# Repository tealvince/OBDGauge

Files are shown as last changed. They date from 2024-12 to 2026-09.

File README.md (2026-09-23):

# vOBD: The K-line Super Gauge
By Vince Lee (c)2024-2026

## Description

This project is a custom OBD cluster gauge and experimentation platform for ECUs 
with a k-line interface, driven by an Arduino nano and intended to be installed 
in a 2" diameter circular pod.

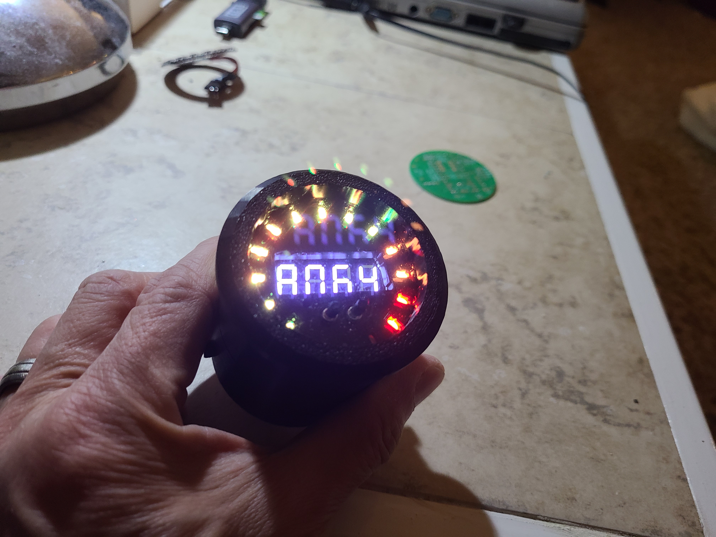
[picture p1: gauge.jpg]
prototype


## Feature overview

* 25 displayable parameters, including instantaneous and cumulative stats
* Metric/Imperial units
* Ability to hide/show individual gauges
* Built-in readiness monitor reader
* Built-in engine code reader
* Built-in menu to clear engine codes
* Adjustable brightness
* Iso-9140, Kwp-2000 (slow) and Kwp-2009 (fast) interfaces
* Numeric display with color led ring
* Persisting of settings with auto-save on power-off
* Auto-detect and cycling of protocols on startup or disconnect
* Custom circuit board layout

## Supported gauges (functionality is vehicle-dependent)

* Battery voltage level
* Accumulated runtime
* Accumulated distance
* Average fuel efficiency
* Average speed
* G-Force
* Wheel Horsepower
* Gear
* NV Ratio (rpm/speed)
* Speed
* Tachometer
* Coolant temp
* Air intake pressure
* Air intake flow
* Throttle percentage
* Engine load
* Timing advance
* Fuel tank level
* Fuel consumption rate
* Air/Fuel trim
* Air/Fuel equivalence ratio
* O2 a/b sensor voltages

## General usage

* Press button 2 to advance to the next gauge.
* Press button 1 to see the previous gauge.
* Long press button 1 to change brightness
* Long press button 2 to open the settings menu.
* Press button 2 to advance to the next item in settings menu.
* Press button 1 to backup to previous item in settings menu.
* Long press button 2 to select an item in the settings menu.

## Settings menu items

* Back (return to main display)

### History
* Erase all (clear cumulative/average gauges)
* Erase cumulative distance
* Erase cumulative fuel
* Erase cumulative time
* Adjust cumulative distance
* Adjust cumulative fuel
* Adjust cumulative time

### Brighness
* brightness levels 1-5

### Gauges
* Toggle current gauge units (metric/us)
* All gauges to SI Units
* All gauges to US Units
* Hide current gauge
* Show gauge (select from list)
* Auto hide/show gauges based on supported PIDs
* See info (dump raw hex data from current gauge)

### Codes
* Check readiness status
* Read codes
* Clear codes

### Values
* Burn adjustment (set multiplier to fine-tune fuel usage/efficiency stats)
* Vehicle weight adjustment (used to calculate HP)
* Show gear NV ratio thresholds
* Start gear auto-detect drive cycle
* Add gear
* Remove gear
* Edit gear threshold (1-8)

### Modes
* Toggle Loop mode (auto-advance gauges) 
* Toggle Demo mode (simulate ECU reponses)
* Toggle Debug mode (show received bytes)
* Enter Sniff mode (listen to K+ line and show received data; use with Y cable and other device)

## Hardware

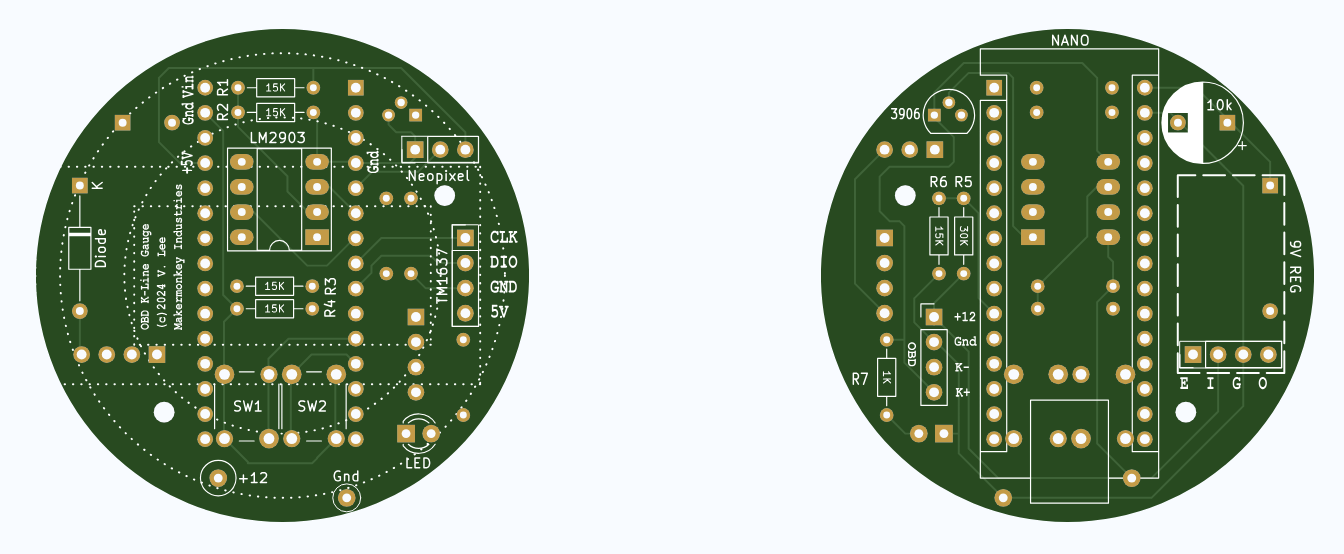
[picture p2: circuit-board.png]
circuit board


* Custom circuit board
* Arduino nano every
* Neopixel 16-LED ring light
* TM1637 4-Digit LED numeric display
* LM2903 Dual comparator IC
* 2N3906 Transistor

## Circuit

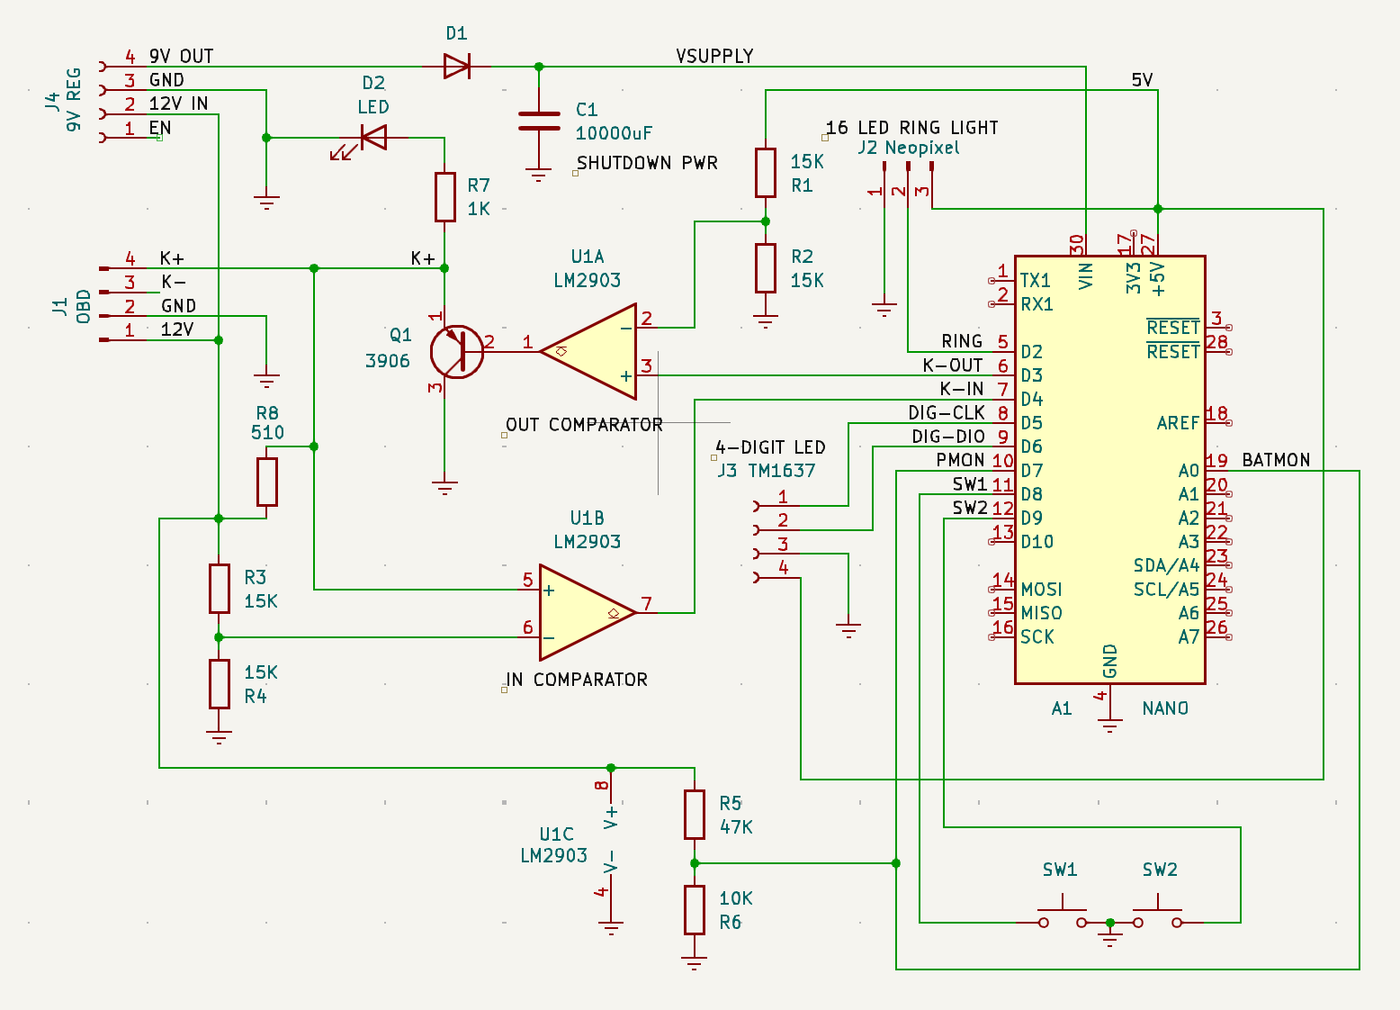
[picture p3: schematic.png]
schematic


To read to and write from the K-Line, a dual comparator chip does the work of converting 
between 5V and 12V logic levels, using voltage dividers to yield 6V and 2.5V reference
voltages.  The output of the "write" comparator goes to a PNP transistor to pull the k-line 
low when sending data back to the PCM, safely sinking more current than the comparator 
can on its own.

To power the arduino, an ignition-switched 12V output is fed to the built-in regulator 
on the Arduino Nano Every (previous iterations used an external voltage regulator with
a plain Arduino Nano, whole upper voltage limit was only 12V).  A large capacitor briefly 
keeps the unit running long enough to save state to persistent memory after the ignition 
is turned off.

## Software

The gauge software is written in C++ with minimal libraries to drive the LED displays.
Serial communication is done with raw bit banging, implementing serial port communication 
purely in software timed off the Arduino microsecond timer.

## Testing

Try out the software or experiment with code changes in a simulated environment using
the following  WOKWI project.  Recommend enabling Demo Mode from the settings menu
since the ECU itself is not simulated:

https://wokwi.com/projects/430523461712229377

## Case

The case and internal spacers and supports are 3D printed.  Stl files are included, as 
well as an svg for the front glass with laser cut holes for the buttons.

Case parts include:

* front glass (laser cut acrylic)
* case body (3d printed)
* case rear (3d printed)
* light mask for led ring (3d printed)
* button extensions (3d printed)
* left and right led digit spacers/supports (3d printed)
* led ring spacer/support (3d printed)

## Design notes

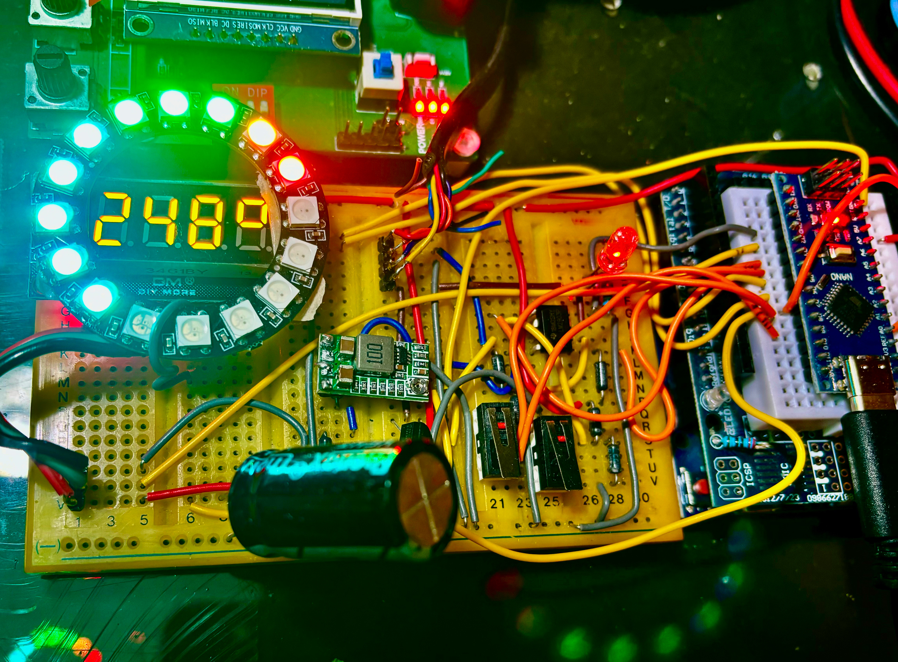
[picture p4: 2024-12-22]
prototype.jpg

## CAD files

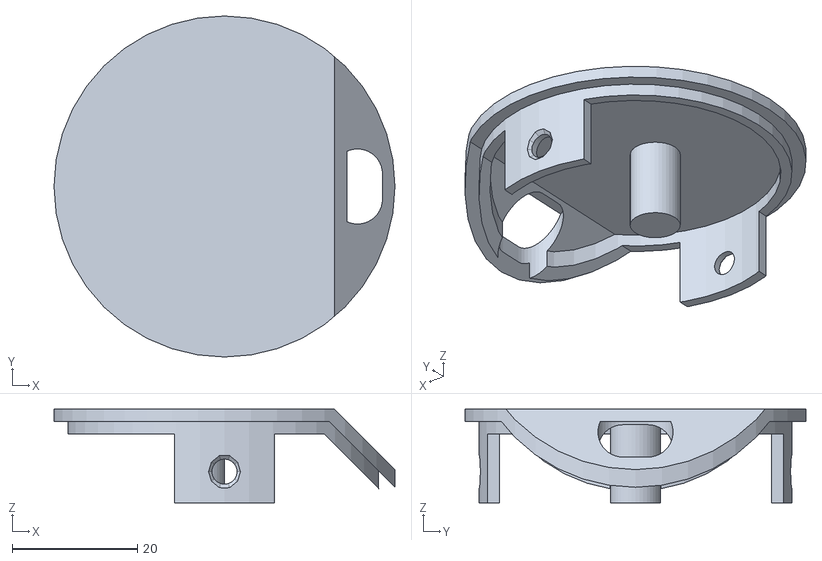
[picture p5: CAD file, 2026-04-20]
src/models/backAngle.stl
54.5 x 54.5 x 15.0

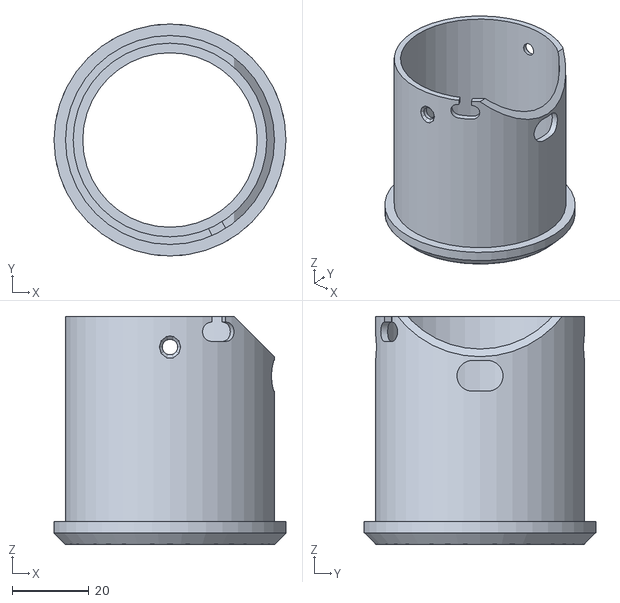
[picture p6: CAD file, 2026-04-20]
src/models/shellAngle.stl
60.5 x 60.5 x 59.5

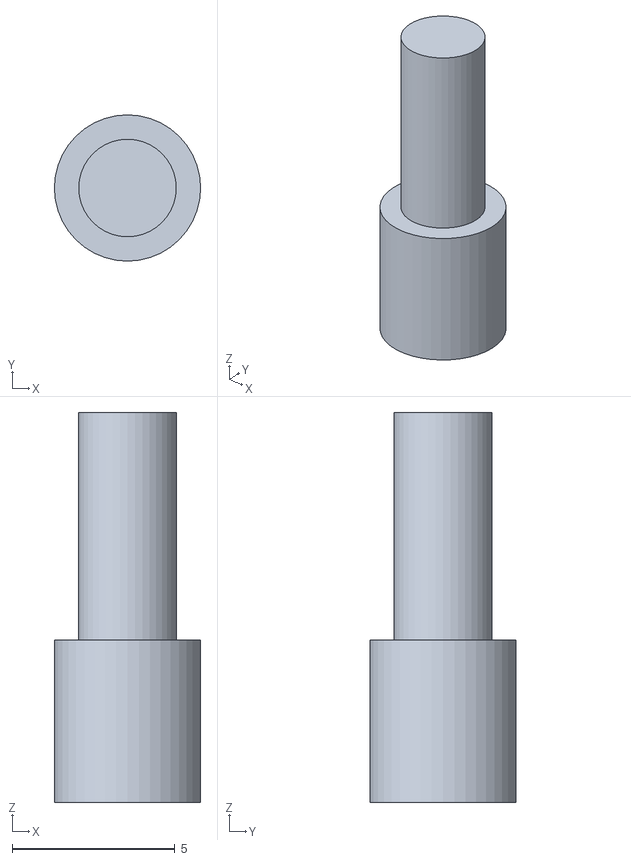
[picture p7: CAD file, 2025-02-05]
src/models/button.stl
4.50 x 4.50 x 12.0

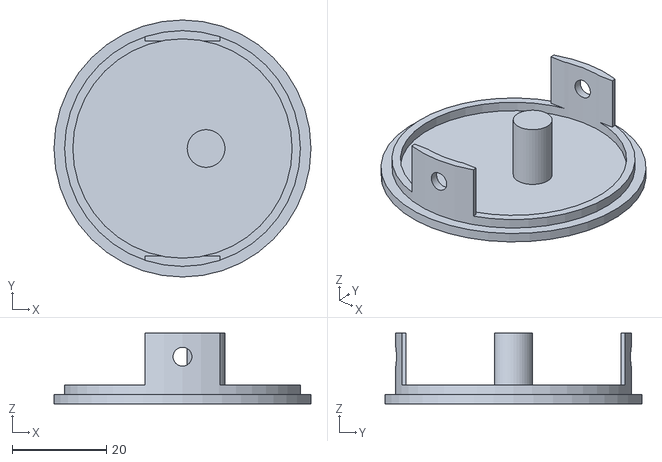
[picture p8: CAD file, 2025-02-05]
src/models/back.stl
54.5 x 54.5 x 15.0

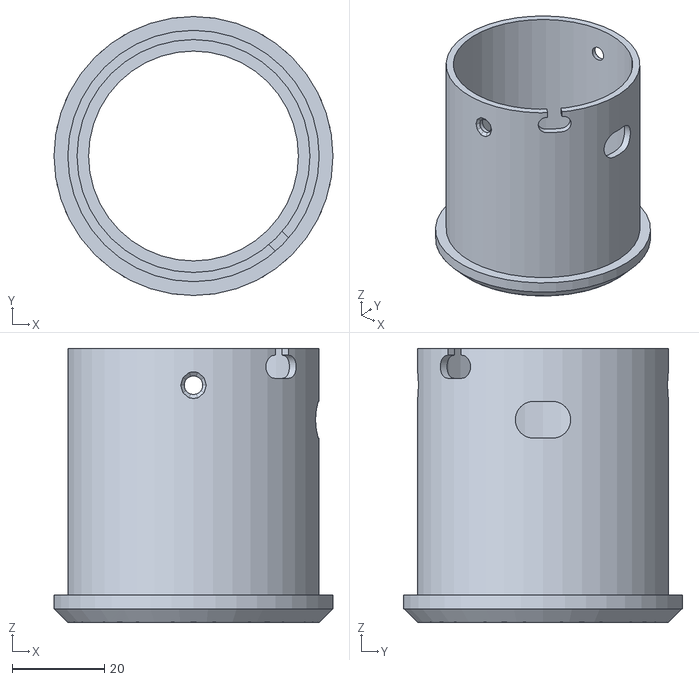
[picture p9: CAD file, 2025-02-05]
src/models/shell.stl
60.5 x 60.5 x 59.5

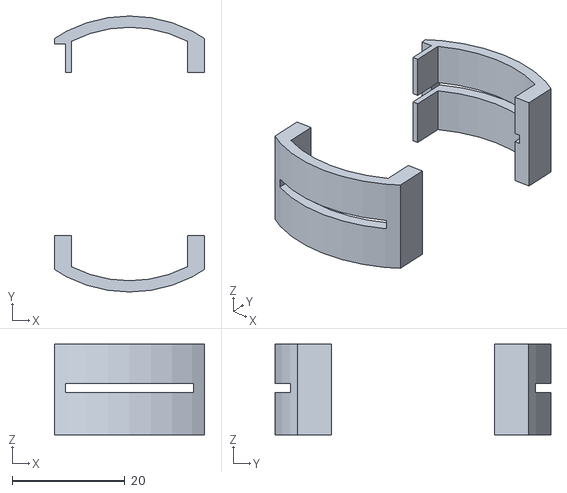
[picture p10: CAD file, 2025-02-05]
src/models/ledSupport.stl
26.6 x 49.0 x 16.1

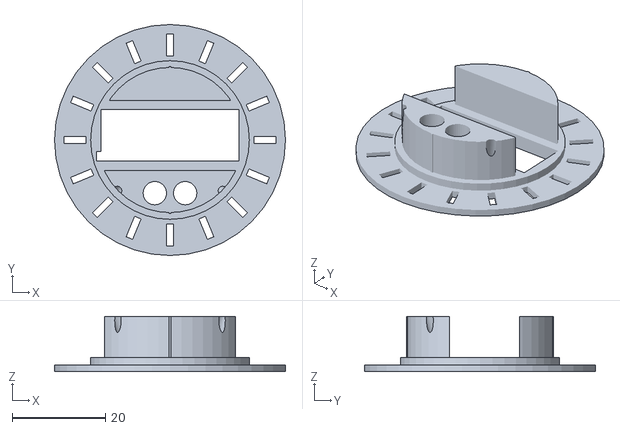
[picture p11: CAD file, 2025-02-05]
src/models/ringSupport.stl
49.5 x 49.5 x 11.8

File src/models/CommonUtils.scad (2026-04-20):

// Rotation
module rotate_x(x,y,z,angle) {
    translate([x,y,z])
        rotate([angle,0,0])
            translate([-x,-y,-z])
                children();
}
module rotate_y(x,y,z,angle) {
    translate([x,y,z])
        rotate([0,angle,0])
            translate([-x,-y,-z])
                children();
}
module rotate_z(x,y,z,angle) {
    translate([x,y,z])
        rotate([0,0,angle])
            translate([-x,-y,-z])
                children();
}

// Oval

module oval(x1, x2, y1, y2, z1, z2) {
	translate([(x1+x2)/2,(y1+y2)/2,z1]) scale([x2-x1,y2-y1,z2-z1]) cylinder(r=0.5,h=1, $fn=40);
}

// Cone
module cone_z(x,y,z1,z2,rad1,rad2) {
   translate([x,y,z1]) {
		cylinder(r1=rad1, r2=rad2, h = z2-z1);
	}
}
module cylinder_x(x1,x2,y,z,rad1,rad2) {

	rounded_box_x(x1,x2,y-rad,y+rad,z-rad,z+rad,rad);
}

// Cylinders

module cylinder_x(x1,x2,y,z,rad) {
	rounded_box_x(x1,x2,y-rad,y+rad,z-rad,z+rad,rad);
}

module cylinder_y(x,y1,y2,z,rad) {
	rounded_box_y(x-rad,x+rad,y1,y2,z-rad,z+rad,rad);
}

module cylinder_z(x,y,z1,z2,rad) {
	rounded_box(x-rad,x+rad,y-rad,y+rad,z1,z2,rad);
}

// Boxes
module rect(x1, x2, y1, y2, z1, z2) {
	box(x1, x2, y1, y2, z1, z2);
}
	
module box(x1, x2, y1, y2, z1, z2) {
	translate([x1,y1,z1]) cube([x2-x1,y2-y1,z2-z1]);
}
                                                                   
// X Boxes

module rounded_box_x(x1, x2, y1, y2, z1, z2, rad) {
	rotate([0,-90,0]) rounded_box_z(z1, z2, y1, y2, -x2, -x1, rad);
}

module half_rounded_box_xup(x1, x2, y1, y2, z1, z2, rad) {
	intersection() {
		box(x1, x2, y1, y2, z1, z2, rad);
		rounded_box_x(x1, x2, y1, y2, z1-rad, z2, rad);
	}
}

module half_rounded_box_xdown(x1, x2, y1, y2, z1, z2, rad) {
	intersection() {
		box(x1, x2, y1, y2, z1, z2, rad);
		rounded_box_x(x1, x2, y1, y2, z1, z2+rad, rad);
	}
}
module half_rounded_box_xfront(x1, x2, y1, y2, z1, z2, rad) {
	intersection() {
		box(x1, x2, y1, y2, z1, z2, rad);
		rounded_box_x(x1, x2, y1, y2+rad, z1, z2, rad);
	}
}

module half_rounded_box_xback(x1, x2, y1, y2, z1, z2, rad) {
	intersection() {
		box(x1, x2, y1, y2, z1, z2, rad);
		rounded_box_x(x1, x2, y1-rad, y2, z1, z2, rad);
	}
}

module quart_rounded_box_xupfront(x1, x2, y1, y2, z1, z2, rad) {
	intersection() {
		box(x1, x2, y1, y2, z1, z2, rad);
		rounded_box_x(x1, x2, y1, y2+rad, z1-rad, z2, rad);
	}
}

module quart_rounded_box_xupback(x1, x2, y1, y2, z1, z2, rad) {
	intersection() {
		box(x1, x2, y1, y2, z1, z2, rad);
		rounded_box_x(x1, x2, y1-rad, y2, z1-rad, z2, rad);
	}
}

module quart_rounded_box_xdownfront(x1, x2, y1, y2, z1, z2, rad) {
	intersection() {
		box(x1, x2, y1, y2, z1, z2, rad);
		rounded_box_x(x1, x2, y1, y2+rad, z1, z2+rad, rad);
	}
}

module quart_rounded_box_xdownback(x1, x2, y1, y2, z1, z2, rad) {
	intersection() {
		box(x1, x2, y1, y2, z1, z2, rad);
		rounded_box_x(x1, x2, y1-rad, y2, z1, z2+rad, rad);
	}
}

// Y Boxes

module rounded_box_y(x1, x2, y1, y2, z1, z2, rad) {
	rotate([90,0,0]) rounded_box_z(x1, x2, z1, z2, -y2, -y1, rad);
}

module half_rounded_box_yup(x1, x2, y1, y2, z1, z2, rad) {
	intersection() {
		box(x1, x2, y1, y2, z1, z2, rad);
		rounded_box_y(x1, x2, y1, y2, z1-rad, z2, rad);
	}
}

module half_rounded_box_ydown(x1, x2, y1, y2, z1, z2, rad) {
	intersection() {
		box(x1, x2, y1, y2, z1, z2, rad);
		rounded_box_y(x1, x2, y1, y2, z1, z2+rad, rad);
	}
}

module half_rounded_box_yleft(x1, x2, y1, y2, z1, z2, rad) {
	intersection() {
		box(x1, x2, y1, y2, z1, z2, rad);
		rounded_box_y(x1, x2+rad, y1, y2, z1, z2, rad);
	}
}

module half_rounded_box_yright(x1, x2, y1, y2, z1, z2, rad) {
	intersection() {
		box(x1, x2, y1, y2, z1, z2, rad);
		rounded_box_y(x1-rad, x2, y1, y2, z1, z2, rad);
	}
}

module quart_rounded_box_yupleft(x1, x2, y1, y2, z1, z2, rad) {
	intersection() {
		box(x1, x2, y1, y2, z1, z2, rad);
		rounded_box_y(x1, x2+rad, y1, y2, z1-rad, z2, rad);
	}
}

module quart_rounded_box_yupright(x1, x2, y1, y2, z1, z2, rad) {
	intersection() {
		box(x1, x2, y1, y2, z1, z2, rad);
		rounded_box_y(x1-rad, x2, y1, y2, z1-rad, z2, rad);
	}
}

module quart_rounded_box_ydownleft(x1, x2, y1, y2, z1, z2, rad) {
	intersection() {
		box(x1, x2, y1, y2, z1, z2, rad);
		rounded_box_y(x1, x2+rad, y1, y2, z1, z2+rad, rad);
	}
}

module quart_rounded_box_ydownright(x1, x2, y1, y2, z1, z2, rad) {
	intersection() {
		box(x1, x2, y1, y2, z1, z2, rad);
		rounded_box_y(x1-rad, x2, y1, y2, z1, z2+rad, rad);
	}
}

// Z Boxes

module rounded_box_z(x1, x2, y1, y2, z1, z2, rad) {
	rect(x1, x2, y1+rad, y2-rad, z1, z2);
	rect(x1+rad, x2-rad, y1, y2, z1, z2);

	oval(x1, x1+rad*2, y1, y1+rad*2, z1, z2);
	oval(x1, x1+rad*2, y2-rad*2, y2, z1, z2);
	oval(x2-rad*2, x2, y2-rad*2, y2, z1, z2);
	oval(x2-rad*2, x2, y1, y1+rad*2, z1, z2);
}

module half_rounded_box_zfront(x1, x2, y1, y2, z1, z2, rad) {
	intersection() {
		box(x1, x2, y1, y2, z1, z2);
		rounded_box_z(x1, x2, y1, y2+rad, z1, z2, rad);
	}
}

module half_rounded_box_zback(x1, x2, y1, y2, z1, z2, rad) {
	intersection() {
		box(x1, x2, y1, y2, z1, z2);
		rounded_box_z(x1, x2, y1-rad, y2, z1, z2, rad);
	}
}

module half_rounded_box_zleft(x1, x2, y1, y2, z1, z2, rad) {
	intersection() {
		box(x1, x2, y1, y2, z1, z2);
		rounded_box_z(x1, x2+rad, y1, y2, z1, z2, rad);
	}
}

module half_rounded_box_zright(x1, x2, y1, y2, z1, z2, rad) {
	intersection() {
		box(x1, x2, y1, y2, z1, z2);
		rounded_box_z(x1-rad, x2, y1, y2, z1, z2, rad);
	}
}

module quart_rounded_box_zfrontleft(x1, x2, y1, y2, z1, z2, rad) {
	intersection() {
		box(x1, x2, y1, y2, z1, z2);
		rounded_box_z(x1, x2+rad, y1, y2+rad, z1, z2, rad);
	}
}

module quart_rounded_box_zfrontright(x1, x2, y1, y2, z1, z2, rad) {
	intersection() {
		box(x1, x2, y1, y2, z1, z2);
		rounded_box_z(x1-rad, x2, y1, y2+rad, z1, z2, rad);
	}
}

module quart_rounded_box_zbackleft(x1, x2, y1, y2, z1, z2, rad) {
	intersection() {
		box(x1, x2, y1, y2, z1, z2);
		rounded_box_z(x1, x2+rad, y1-rad, y2, z1, z2, rad);
	}
}

module quart_rounded_box_zbackright(x1, x2, y1, y2, z1, z2, rad) {
	intersection() {
		box(x1, x2, y1, y2, z1, z2);
		rounded_box_z(x1-rad, x2, y1-rad, y2, z1, z2, rad);
	}
}

// Legacy

module rounded_box(x1, x2, y1, y2, z1, z2, rad) {
	rounded_box_z(x1, x2, y1, y2, z1, z2, rad);
}

module half_rounded_box(x1, x2, y1, y2, z1, z2, rad) {
	half_rounded_box_zfront(x1, x2, y1, y2, z1, z2, rad);
}

module half_rounded_box_x(x1, x2, y1, y2, z1, z2, rad) {
	half_rounded_box_xfront(x1, x2, y1, y2, z1, z2, rad);
}

module half_rounded_box_y(x1, x2, y1, y2, z1, z2, rad) {
	half_rounded_box_yup(x1, x2, y1, y2, z1, z2, rad);
}



// Frustum

// 1(5)  2(6)
// 0(4)  3(7)
module frustrum(dx1,dy1,dx2,dy2,dz1,dz2) {
	frustum(dx1,dy1,dx2,dy2,dz1,dz2);
}
	
module frustum(dx1,dy1,dx2,dy2,dz1,dz2) {
	polyhedron( points=[[-dx1/2,-dy1/2,dz1],
						 [-dx1/2, dy1/2,dz1],
						 [ dx1/2, dy1/2,dz1],
						 [ dx1/2,-dy1/2,dz1],
						 [-dx2/2,-dy2/2,dz2],
						 [-dx2/2, dy2/2,dz2],
						 [ dx2/2, dy2/2,dz2],
						 [ dx2/2,-dy2/2,dz2]],
				 triangles=[[0,2,1],[0,3,2],
							 [0,4,7],[0,7,3],
							 [3,7,6],[3,6,2],
							 [2,6,5],[2,5,1],
							 [1,5,4],[1,4,0],
							 [4,5,6],[4,6,7]] );
}

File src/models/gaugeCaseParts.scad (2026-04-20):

include <commonutils.scad>

button_spacing = 6.5;
button_diam = 4+1;
button_y = -7.5-4.89+1;

ring_retainer_lip_diam = 34;
ring_retainer_lip_thick = 3;
ring_retainer_inner_diam = 30-1.2+2.3;
ring_retainer_height = 10.8-2;
ring_retainer_notch_height = 31.5;
ring_retainer_notch_width = 0.5;

ring_con_x = 12.6;
ring_con_y = 22.5/2;
ring_con_w = 10;
ring_con_h = 3.5;

led_cy = 1;
led_width = 31+.5;
led_height = 15;//-2.7;
led_lip_v_width = 1;
led_lip_h_width = 2;

light_dx = -9;
light_dy = -8.5;
light_hole_diam = 2;
light_rx = 15;
light_ry = -15;

shell_in_lip = 2.5;
shell_out_lip = 3;
shell_diam = 50+0.5;
shell_height = 40+15-4.5;
shell_thick = 2;
shell_glass_thick = 3;
shell_front_thick = 6;
shell_holes_dz = 8;
shell_holes_diam = 4;

usb_depth = 8;
usb_width = 12;
usb_z = 47-3;

// Angled back
back_angle = 45;
back_angle_x = shell_diam/2;
back_angle_z = usb_z+usb_depth/2+3;

obd_width = 9.3;
obd_depth = 5;
obd_angle = 180-45-90+17;
obd_z = shell_height + shell_glass_thick + shell_front_thick + shell_thick - obd_depth - 1;

//button();
// ring_retainer();

color("blue") shell();

//rotate([180])
//  translate([0,0,20])
//      color("red") back();

//led_support();
//  grille();

module led_support() {    
    diam = 49;
    height = 7.5;
    thick = 2;
    depth = 10;
    
    board_width = 22.15+.25+.25;
    board_thick = 1.6;

    difference() {
        intersection() {
            cylinder_z(0,0,0,height+board_thick+thick+5, diam/2);
            box(-board_width/2-thick, board_width/2+thick, -100, 100, -100, 100);
        }
        intersection() {
            cylinder_z(0,0,0,height+board_thick+thick+5, diam/2-thick);
            box(-board_width/2+1, board_width/2-1, -100, 100, -100, 100);
        }
        box(-board_width/2, board_width/2, -100, 100, height, height+board_thick);
        box(-100,100, -diam/2+depth, diam/2-depth, -100,100);
        box(-100,-board_width/2, 0, diam/2-5, -100,100);
    }
}

module grille() {
    inner_diam = 34;
    outer_diam = 49.5;
    thick = 2.8;
    slit = 2.5-1;
    
    translate([0,0,-ring_retainer_lip_thick])
    difference() {
        cylinder_z(0,0,0,thick/2,outer_diam/2);
        cylinder_z(0,0,thick/2,thick,outer_diam/2-2);
        cylinder_z(0,0,0,thick,inner_diam/2);
        for (angle = [0: 360/16: 360]) rotate([0,0,angle]) {
            box(-slit/2,slit/2, inner_diam/2+1, outer_diam/2-2, 0,thick+2);
        }
    }
}

module back() {
    
    // center post support
    cylinder_z(-4, 0,
        shell_height + shell_glass_thick + shell_front_thick - 13, 
        shell_height + shell_glass_thick + shell_front_thick + shell_thick,
                4);

    // Angled back
    difference() {
        union() {
            // outer
            difference() {
                intersection() {
                    translate([back_angle_x,0,back_angle_z])
                        rotate([0, back_angle, 0])
                            box(-100,100,-100,100,0,100);
                    cylinder_z(0,0,
                        0, 
                        shell_glass_thick + shell_front_thick+shell_height+shell_thick,
                        shell_diam/2+shell_thick);
                }

                translate([back_angle_x,0,back_angle_z])
                    rotate([0, back_angle, 0])
                        box(-100,100,-100,100,shell_thick,100);
            }       
            // inner 
            intersection() {
                difference() {
                    cylinder_z(0,0,
                        0, 
                        shell_glass_thick + shell_front_thick+shell_height+shell_thick,
                        shell_diam/2-.25);
                    cylinder_z(0,0,
                        0, 
                        shell_glass_thick + shell_front_thick+shell_height+shell_thick,
                        shell_diam/2-shell_thick);
                }
                translate([back_angle_x,0,back_angle_z])
                    rotate([0, back_angle, 0])
                        box(-100,100,-100,100,-shell_thick,.01);
            }        
        }
        rounded_box_z(shell_diam/2-usb_depth, shell_diam/2,
            -usb_width/2, usb_width/2, -100,100, usb_depth/2);
    }
    
    difference() {
        union() {
            // Inner
            cylinder_z(0,0,
                shell_height+ shell_glass_thick + shell_front_thick-shell_holes_dz-5, 
                shell_glass_thick + shell_front_thick+shell_height+shell_thick,
                shell_diam/2-.25);
            
            // lid
            cylinder_z(0,0,
                shell_glass_thick + shell_front_thick+shell_height,
                shell_glass_thick + shell_front_thick+shell_height+shell_thick,
                shell_diam/2+shell_thick);

        }
        // Angled Back
        translate([back_angle_x,0,back_angle_z])
            rotate([0, back_angle, 0])
                box(-100,100,-100,100,shell_thick,100);

        // tab cutouts
        box(-100,-8, -100,100, 0, shell_height+ shell_glass_thick + shell_front_thick-shell_thick);
        box(8, 100, -100,100, 0, shell_height+ shell_glass_thick + shell_front_thick- shell_thick);
        box(-100, 100, -shell_diam/2+2.5+2, shell_diam/2-2.5-2, 0, shell_height+ shell_glass_thick + shell_front_thick- shell_thick);

        // inner circle
            cylinder_z(0,0,0,
                    shell_glass_thick + shell_front_thick+shell_height,
                    shell_diam/2-shell_thick);
        
        // Screw holes
        translate([0, -shell_diam/2-shell_thick+2, 
            shell_height+ shell_glass_thick + shell_front_thick-shell_holes_dz]) 
                rotate([-90]) shell_hole();
        mirror([0,1,0]) 
            translate([0, -shell_diam/2-shell_thick+2, 
            shell_height+ shell_glass_thick + shell_front_thick-shell_holes_dz]) 
                rotate([-90]) shell_hole();
    }
}    

module shell() {
    difference(){
        union() {
            cylinder_z(0,0,0, 
                shell_height + shell_glass_thick + shell_front_thick,
                shell_diam/2+shell_thick);
            cylinder(
                r1 = shell_diam/2+shell_thick, 
                r2 = shell_diam/2+shell_thick+shell_out_lip,
                h = shell_front_thick/2);
            cylinder_z(0,0,shell_front_thick/2-.01, 
                shell_front_thick,
                shell_diam/2+shell_thick+shell_out_lip);
        }
        cylinder_z(0,0,
            shell_front_thick-.01, 
            shell_glass_thick + shell_front_thick+shell_height+.01,
            shell_diam/2);
        cylinder_z(0,0,-0.01,
            shell_front_thick,
            shell_diam/2-shell_in_lip);

        // usb port
        rounded_box_x(0, 100, -usb_width/2, usb_width/2,
            usb_z-usb_depth/2, usb_z+usb_depth/2, usb_depth/2);
        
        // obd port
        rotate([0,0,obd_angle]) union() {
            rounded_box_x(0, 100, -obd_width/2, obd_width/2,
                obd_z-obd_depth/2, obd_z+obd_depth/2, obd_depth/2);
            box(0, 100, -2, 2,
                obd_z-obd_depth/2, obd_z+obd_depth/2+5);
        }
        
        // Screw holes
        translate([0, -shell_diam/2-shell_thick, 
            shell_height+ shell_glass_thick + shell_front_thick-shell_holes_dz]) 
                rotate([-90]) shell_hole();
        mirror([0,1,0]) 
            translate([0, -shell_diam/2-shell_thick, 
            shell_height+ shell_glass_thick + shell_front_thick-shell_holes_dz]) 
                rotate([-90]) shell_hole();
        
        // Angled back
        
        translate([back_angle_x,0,back_angle_z])
            rotate([0, back_angle, 0])
                box(-100,100,-100,100,0,100);
    }
} 

module shell_hole() {
        cylinder_z(0,0,0,
            shell_thick*2+1,
            shell_holes_diam/2);
        cylinder(
            r1 = shell_holes_diam/2+shell_thick/2, 
            r2 = shell_holes_diam/2,
            h = shell_thick/2);

}

module button() {
    cylinder_z(0,0,0,5, 4.5/2);
    cylinder_z(0,0,0,12, 3/2);

}
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

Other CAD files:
src/models/shellAngleFlip.stl

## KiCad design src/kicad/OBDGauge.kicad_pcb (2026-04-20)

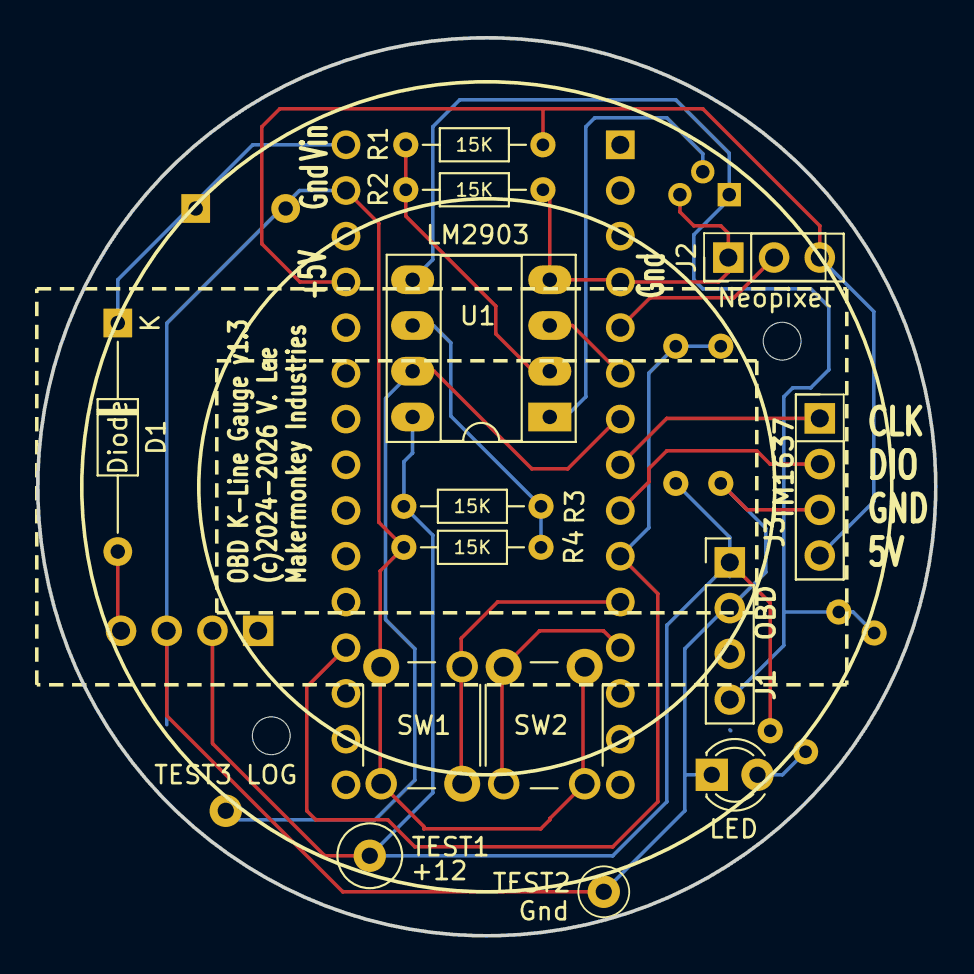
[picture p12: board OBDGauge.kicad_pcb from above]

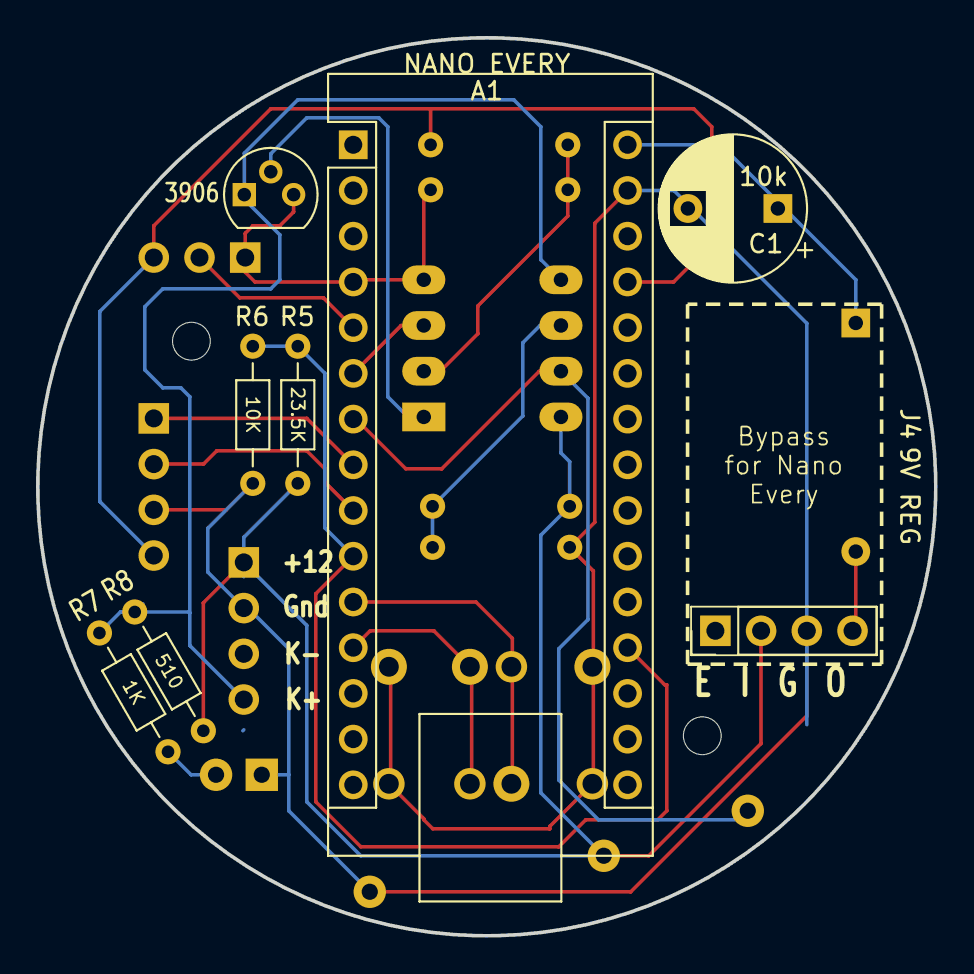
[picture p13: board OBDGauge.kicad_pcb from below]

Board: 2 copper layers, 49.9 x 49.9 mm, 25 parts (8 on the bottom side), 18 nets.

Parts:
A1: NANO EVERY; Arduino_Nano
C1: 10000uF; CP_Radial_D8.0mm_P5.00mm
D1: Diode; D_DO-35_SOD27_P12.70mm_Horizontal
D2: LED; LED_D3.0mm
HOLE1, HOLE2: MountingHole_2.1mm
J1: OBD; PinHeader_1x04_P2.54mm_Vertical
J2: Neopixel; PinHeader_1x03_P2.54mm_Vertical
J3: TM1637; PinHeader_1x04_P2.54mm_Vertical
J4: 9V REG; PinHeader_1x04_P2.54mm_Vertical
Q1: 3906; TO-92
R1, R2, R3, R4, R6: 15K; R_Axial_DIN0204_L3.6mm_D1.6mm_P7.62mm_Horizontal
R5: 30K; R_Axial_DIN0204_L3.6mm_D1.6mm_P7.62mm_Horizontal
R7: 1K; R_Axial_DIN0204_L3.6mm_D1.6mm_P7.62mm_Horizontal
R8: 10K; R_Axial_DIN0204_L3.6mm_D1.6mm_P7.62mm_Horizontal
SW1: SW1; SW_PUSH_6mm_H8.5mm
SW2: SW2; SW_PUSH_6mm_H8.5mm
TEST1: +12; TestPoint_Loop_D3.50mm_Drill0.9mm_Beaded
TEST2, TEST3 LOG: GND
U1: LM2903; DIP-8_W7.62mm_Socket_LongPads

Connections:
/5V: A1.27 (+5V), J2.3, J3.4, R1.2
/9V OUT: D1.2 (A), J4.4
/12V: J1.1, J4.2, R3.1, R5.1, R8.2, TEST1.1, U1.8 (V+)
/BATMON: A1.10 (D7), A1.19 (A0), R5.2, R6.2
/DIG-CLK: A1.8 (D5), J3.1
/DIG-DIO: A1.9 (D6), J3.2
/K+: J1.4, Q1.1 (E), R7.1, R8.1, U1.5 (+)
/K-IN: A1.7 (D4), TEST3 LOG.1, U1.7
/K-OUT: A1.6 (D3), U1.3 (+)
/RING: A1.5 (D2), J2.2
/SW1: A1.11 (D8), SW1.2
/SW2: A1.12 (D9), SW2.2
/VSUPPLY: A1.30 (VIN), C1.1, D1.1 (K)
GNDREF: A1.4 (GND), A1.29 (GND), C1.2, D2.1 (K), J1.2, J2.1, J3.3, J4.3, Q1.3 (C), R2.2, R4.1, R6.1, SW1.1, SW2.1, TEST2.1, U1.4 (V-)
unnamed: D2.2 (A), R7.2
unnamed: Q1.2 (B), U1.1
unnamed: R1.1, R2.1, U1.2 (-)
unnamed: R3.2, R4.2, U1.6 (-)

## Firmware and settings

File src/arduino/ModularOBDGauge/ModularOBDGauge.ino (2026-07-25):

#include "Environment.h"
#include "VDigits.h"
#include "VDisplayables.h"
#include "VRing.h"

//
// MODULAROBDGAUGE.INO
//

#define DIGITS_PIN_CLK      5
#define DIGITS_PIN_DIO      6
#define DIGITS_BRIGHTNESS_MAX 7
#define DIGITS_BRIGHTNESS_MIN 2

#define OBD_OUT_PIN         3
#define OBD_IN_PIN          4

#define POWER_PIN           7
#define POWER_ANALOG_PIN    A0

#define RING_PIN_CONTROL    2
#define RING_LIGHT_COUNT    16
#define RING_ROTATION_OFFSET (WOKWI ? 7 : 0)
#define RING_STATUS_COUNT   3
#define RING_BRIGHTNESS     25
#define RING_BRIGHTNESS_MAX (WOKWI ? 255 : 40)
#define RING_BRIGHTNESS_MIN 4

#define SWITCH_PIN_1        9
#define SWITCH_PIN_2        8
#define LED_PIN             13

VDigits vdigits;
VDisplayables vdisplayables;
VRing vring;

// Forward declarations
bool ap_isControlsButton1Down();
bool ap_isControlsButton2Down();
void ap_menuItemHighlight(int current, char color, int count, MenuDataSource *ds);
void ap_menuItemShowTitle(char *title);
int  ap_getDisplayBarCount(void);
void ap_setDisplayBarColor(int index, unsigned char color);
void ap_showDisplayBar();
void ap_showDisplayFloatValue(float num, int decimals, int suffix, bool addPlus);
void ap_showDisplayStatusState(bool connecting, bool resetting, int errorCount, int connectionErrorCount, int protocolIndex);
void ap_showDisplayStatusString(char *text);
void ap_showDisplayStatusString_P(char *ptext);
void ap_showSweep(char color, int mode);
void ap_setDisplayBrightness(int brightness);
void ap_smartDelay(unsigned long wait);

struct MenuControlsProvider app_menuControlsProvider = {
  ap_isControlsButton1Down,
  ap_isControlsButton2Down,
  ap_smartDelay
};

struct MenuDisplayProvider app_menuDisplayProvider = {
  ap_menuItemHighlight,
  ap_menuItemShowTitle,
};

struct DisplayablesOutputProvider app_displayablesOutputProvider = {
  ap_getDisplayBarCount,
  ap_setDisplayBarColor,
  ap_showDisplayBar,
  ap_showDisplayFloatValue,
  ap_showDisplayStatusState,
  ap_showDisplayStatusString,
  ap_showDisplayStatusString_P,
  ap_showSweep,
  ap_setDisplayBrightness,
};

void setup() {
 
  // Setup
  pinMode(POWER_PIN, INPUT);
  pinMode(SWITCH_PIN_1, INPUT_PULLUP);
  pinMode(SWITCH_PIN_2, INPUT_PULLUP);
  vdigits.setup(DIGITS_PIN_CLK, DIGITS_PIN_DIO);
  vring.setup(RING_PIN_CONTROL, RING_LIGHT_COUNT, RING_BRIGHTNESS, RING_ROTATION_OFFSET);

  ap_showDisplayStatusString_P(PSTR("VObd"));
  ap_showSweep('c', SWEEP_MODE_RIGHT_LEFT);
  ap_smartDelay(800);
  ap_showDisplayStatusString_P(PSTR(" " BUILD_VERSION));
  ap_smartDelay(800);
  vring.clear();

  vdisplayables.setup(OBD_IN_PIN, OBD_OUT_PIN, POWER_ANALOG_PIN, &app_displayablesOutputProvider, &app_menuDisplayProvider, &app_menuControlsProvider);
}

void loop() {
  vdisplayables.mainLoop();
}

///////////////////////////////////////////////////////////////
// APP GLUE
///////////////////////////////////////////////////////////////

//------------------------------------------------------
// Private
//------------------------------------------------------

#define BUTTON_DEBOUNCE_COUNT 12
static bool ap_button1LastState = false;
static bool ap_button2LastState = false;

bool ap_isControlsButton1Down() {
  bool state = !digitalRead(SWITCH_PIN_1);
  digitalWrite(LED_PIN, state);

  if (state != ap_button1LastState) {
    for (int i=0; i<BUTTON_DEBOUNCE_COUNT; i++) {
      if (!digitalRead(SWITCH_PIN_1) != state) return ap_button1LastState;
      ap_smartDelay(1);
    }
    return ap_button1LastState = state;
  }

  // Kind of hacky, but ping when reading buttons to keep connection alive
  vdisplayables.ping();

  return ap_button1LastState;
}

bool ap_isControlsButton2Down() {
  bool state = !digitalRead(SWITCH_PIN_2);
  if (state != ap_button2LastState) {
    for (int i=0; i<BUTTON_DEBOUNCE_COUNT; i++) {
      if (!digitalRead(SWITCH_PIN_2) != state) return ap_button2LastState;
      ap_smartDelay(1);
    }
    return ap_button2LastState = state;
  }
  return ap_button2LastState;
}

void ap_menuItemHighlight(int current, char color, int count, MenuDataSource *ds) {
  int iCur = (current + RING_STATUS_COUNT) % RING_LIGHT_COUNT;

  // Show current entry in ring
  for (int i = 0; i < RING_LIGHT_COUNT; i++) {
    if (i == iCur) {
      vring.setPixelColor(i, color);
    } else if (i >= RING_STATUS_COUNT && i < RING_STATUS_COUNT + count || (RING_STATUS_COUNT + count > RING_LIGHT_COUNT && i < (RING_STATUS_COUNT + count) % RING_LIGHT_COUNT)) {
      int delta = i - iCur;

      if (delta > RING_LIGHT_COUNT/2 && current + delta - RING_LIGHT_COUNT >= 0) {
        delta -= RING_LIGHT_COUNT;
      } else if (delta < -RING_LIGHT_COUNT/2 && current + delta + RING_LIGHT_COUNT < count) {
        delta += RING_LIGHT_COUNT;
      }
      int index = current + delta;
      // Show wrapping limits as gap      
      if (index == -1 || index == count) {
        vring.setPixelColor(i, 'k');
      } else if (index == -2 || index == count+1) {
        vring.setPixelColor(i, '-');
      } else if (index == -3 || index == count+2) {
        vring.setPixelColor(i, '+');
      } else {
        vring.setPixelColor(i, index >=0 && index < count ? ds->getItemColor(index, current, ds) : ds->defaultColor);
      }
    } else {
      vring.setPixelColor(i, 'k');
    }
  }
  vring.show();
}

void ap_menuItemShowTitle(char *title) {
  vdigits.showString(title, true);
}

int ap_getDisplayBarCount(void) {
  return RING_LIGHT_COUNT - RING_STATUS_COUNT;
}

void ap_setDisplayBarColor(int index, unsigned char color) {
  vring.setPixelColor(index + RING_STATUS_COUNT, color);
}

void ap_showDisplayBar() {
  vring.show();
}

void ap_showDisplayFloatValue(float num, int dig, int suf, bool addPlus) {
  char sufBuf[2];
  char preBuf[2];
  char *prefix = preBuf; prefix[0] = (num < 0) ? '-' : addPlus ? '+' : 0;

  char suffix = 0;
  unsigned long whole = 0;
  unsigned long frac = 0;
  int fracdig = 0;

  sufBuf[1] = 0;
  preBuf[1] = 0;
  num = fabs(num);

  if (num > 999000000) {
    whole = num/1000000000;
    frac = (num-whole*1000000000)/100000000;
    fracdig = 1;
    suffix = 'B';
  } else if (num > 999000) {
    whole = num/1000000;
    frac = (num-whole*1000000)/100000;
    fracdig = 1;
    suffix = 'M';
  } else if (num > 9999) {
    whole = num/1000;
    frac = (num-whole*1000)/100;
    fracdig = 1;
    suffix = 'k';
  } else {
    whole = num;
    if (dig > 0) {
      float diff = fabs(num) - floor(fabs(num));
      for (int i=0; i<dig; i++) {
        diff *= 10;
      }
      frac = diff;
      fracdig = dig;
    }
  }

  char buf[30];
  char tmp[30];

  strcpy(buf, prefix);
  itoa(whole, buf+strlen(buf), 10);

  int maxDigits = 4;

  // Override default suffix if set
  sufBuf[0] = suffix ?: suf;

  if (strlen(buf) + strlen(sufBuf) + 1 <= maxDigits && ((strlen(sufBuf) && suffix) || dig)) {
    maxDigits++;
    strncat(buf, ".", sizeof(buf)-1);
    itoa(frac, tmp, 10);
    for (int i=strlen(tmp); i<fracdig; i++) {
      strncat(buf, "0", sizeof(buf)-1);
    }
    strncat(buf, tmp, sizeof(buf)-1);
  }

  // Right justify
  int space = maxDigits - strlen(buf) - strlen(sufBuf);
  space = max(0, space);
  tmp[0] = tmp[1] = tmp[2] = tmp[3] = ' ';
  tmp[4] = 0;
  strcpy(tmp+space, buf);

  strncat(tmp, sufBuf, sizeof(tmp)-1);
  vdigits.showString(tmp, true);
}

void ap_showDisplayStatusState(bool connecting, bool resetting, int errorCount, int connectionErrorCount, int protocolIndex) {
  bool powerOn = digitalRead(POWER_PIN);

  for (int i=0; i<RING_STATUS_COUNT; i++) {
    if (!powerOn) {
      vring.setPixelColor(i, 'o');
    } else if (connecting) {
      vring.setPixelColor(RING_STATUS_COUNT-i-1, (i == protocolIndex % RING_STATUS_COUNT) ? 'b' : 'I');
    } else if (resetting) {
      vring.setPixelColor(i, i <= RING_STATUS_COUNT-connectionErrorCount ? 'V' : 'p');
    } else {
      vring.setPixelColor(RING_STATUS_COUNT-i-1, i < errorCount ? 'R' : 'k');
    }
  }
  vring.show();
}

void ap_showDisplayStatusString(char *text) {
  vdigits.showString(text, true);
}

void ap_showDisplayStatusString_P(char *ptext) {
  char text[20];
  strcpy_P(text, ptext);
  ap_showDisplayStatusString(text);
}

void ap_showSweep(char color, int mode) {
  int lightCount = ap_getDisplayBarCount();

  switch(mode) {
    case SWEEP_MODE_UP:
      for (int j = 0; j <= lightCount/2; j++) {
        for (int i = 0; i < lightCount; i++) {    
          ap_setDisplayBarColor(i, i==j || i==lightCount-1-j ? color : 'k');
        }
        ap_showDisplayBar(); 
        ap_smartDelay(40);
      }
      ap_setDisplayBarColor(lightCount/2, 'k');
      break;

    case SWEEP_MODE_DOWN:
      for (int j = lightCount/2; j >= 0; j--) {    
        for (int i = 0; i < lightCount; i++) {    
          ap_setDisplayBarColor(i, i==j || i==lightCount-1-j ? color : 'k');
        }
        ap_showDisplayBar(); 
        ap_smartDelay(40);
      }
      ap_setDisplayBarColor(0, 'k');
      ap_setDisplayBarColor(lightCount-1, 'k');
      break;

    case SWEEP_MODE_RIGHT_LEFT:
    default:
      for (int j = 0; j < lightCount; j++) {    
        for (int i = 0; i < lightCount; i++) {    
          ap_setDisplayBarColor(i, i==j ? color : 'k');
        }
        ap_showDisplayBar(); 
        ap_smartDelay(40);
      }
      for (int j = lightCount-1; j >= 0; j--) {    
        for (int i = 0; i < lightCount; i++) {    
          ap_setDisplayBarColor(i, i==j ? color : 'k');
        }
        ap_showDisplayBar(); 
        ap_smartDelay(40);
      }
      ap_setDisplayBarColor(0, 'k');
      break;
  }
  ap_showDisplayBar(); 
}

void ap_setDisplayBrightness(int brightness) {
  vring.setBrightness(RING_BRIGHTNESS_MIN + (RING_BRIGHTNESS_MAX - RING_BRIGHTNESS_MIN) * brightness/100);
  vdigits.setBrightness(DIGITS_BRIGHTNESS_MIN + (DIGITS_BRIGHTNESS_MAX - DIGITS_BRIGHTNESS_MIN) * brightness/100);
}

static bool ap_lastPowerOn;
void ap_smartDelay(unsigned long wait) {
  unsigned long start = millis();
  while (1) {
    // Detect changes in input power
    bool powerOn = digitalRead(POWER_PIN);
    if (ap_lastPowerOn != powerOn) {
      ap_lastPowerOn = powerOn;
      if (!powerOn) {
        vdigits.showString("Lo-V", true);
        if (vdisplayables.savePersistedState()) {
          vdigits.showString("Save", true);
          delay(1000);
        }
      }
    }

    unsigned long time = millis();
    if (time < start || time >= start + wait) return;

    // Don't block UI for extended periods of time
    if (time >= start + 100 && ap_isControlsButton1Down()) return;
  }
}

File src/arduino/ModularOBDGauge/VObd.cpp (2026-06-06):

#include "VDisplayables.h" // for sweep enums
#include "VObd.h"
#include <Arduino.h>

///////////////////////////////////////////////////////////////
// VOBD.CPP
// Obd protocol handling
///////////////////////////////////////////////////////////////

// KWP Key value bits
#define KWP_KEY1_LENGTH_IN_FORMAT_BYTE_SUPPORTED     0x01
#define KWP_KEY1_ADDITIONAL_LENGTH_BYTE_SUPPORTED    0x02
#define KWP_KEY1_ONE_BYTE_HEADER_SUPPORTED           0x04
#define KWP_KEY1_TARGET_SOURCE_BYTE_SUPPORTED        0x08
#define KWP_KEY1_NORMAL_TIMING_SUPPORTED             0x10
#define KWP_KEY1_EXTENDED_TIMING_SUPPORTED           0x20
#define KWP_KEY1_UNUSED_ALWAYS_ONE                   0x40
#define KWP_KEY1_PARITY                              0x80

#define KWP_MESSAGE_FORMAT_ONE_BYTE_HEADER_LENGTH_IN_FORMAT   0
#define KWP_MESSAGE_FORMAT_ONE_BYTE_HEADER_ADDITIONAL_LENGTH  1
#define KWP_MESSAGE_FORMAT_ADDRESS_HEADER_LENGTH_IN_FORMAT    2
#define KWP_MESSAGE_FORMAT_ADDRESS_HEADER_ADDITIONAL_LENGTH   3

//------------------------------------------------------
// Public (Connect)
//------------------------------------------------------

extern void VObd::setup(int in, int out, void (*delay)(unsigned long), struct ObdOutputProvider *optionalOutputProvider) {
  output = optionalOutputProvider;
  vserial.setup(in, out, delay);
  smartDelay = delay;
}

extern void VObd::connect(int proto, bool demoMode) {
  switch (proto) {
    case OBD_PROTOCOL_ISO_9141:
    case OBD_PROTOCOL_KWP_SLOW:
      if (proto = kwpSlowInit(proto, demoMode)) {
        protocol = proto;
      }
      break;
    case OBD_PROTOCOL_KWP_FAST:
      if (proto = kwpFastInit(proto)) {
        protocol = proto;
      }
      break;
  }
  if (protocol) {
    lastPidRequestTime = millis();
  }
}

extern void VObd::disconnect() {
  protocol = 0;
}

extern bool VObd::isConnected() {
  return protocol != 0;
}

extern void VObd::ping() {
  // Periodically send request to keep connection alive
  if (isConnected() && ((long)(millis() - lastPidRequestTime)) > QUERY_MAX_INTERVAL) {
      sendPidRequest(0x00, 1);
  }
}

extern bool VObd::resetConnection() {
  unsigned long start = micros();

  // Send a bunch of nulls to force the ECU to wait for initialization.
  // By happenstance this was found to work on ECU simulator.  Unsure
  // how effective or necessary this is on a real ECU.
  vserial.sendByteRepeatedly(0, 256, 10400L, 0);
  smartDelay(2600);
}

//------------------------------------------------------
// Public (Query)
//------------------------------------------------------

extern int VObd::sendPidRequest(unsigned char pid, int mode) {
  char bytes[20];
  int count = 0;
  int length = (pid || (mode == 1)) ? 2 : 1;
  unsigned long time = millis();
  long wait = lastPidRequestTime + QUERY_MIN_INTERVAL - time;

  // Enforce minimum time between receiving last request and sending new one
  if (wait > 0 && wait <= QUERY_MIN_INTERVAL) {
    smartDelay(wait);
  }
  // Save time for pinging
  lastPidRequestTime = time;

  switch (protocol) {
    case OBD_PROTOCOL_ISO_9141:
      // Example: 68 6A F1 01 00 C4 

      bytes[count++] = 0x68;  // Diagnostic request
      bytes[count++] = 0x6A;  // Target (ECU)
      bytes[count++] = 0xF1;  // Source (Diagnostic device)
      break;

    case OBD_PROTOCOL_KWP_SLOW:
    case OBD_PROTOCOL_KWP_FAST:

      // One byte header with length in format
      if ((keyByte1 & KWP_KEY1_ONE_BYTE_HEADER_SUPPORTED) && (keyByte1 & KWP_KEY1_LENGTH_IN_FORMAT_BYTE_SUPPORTED)) {
        messageFormat = KWP_MESSAGE_FORMAT_ONE_BYTE_HEADER_LENGTH_IN_FORMAT;
        bytes[count++] = length;
      }

      // One byte header with external length byte
      else if ((keyByte1 & KWP_KEY1_ONE_BYTE_HEADER_SUPPORTED)) {
        messageFormat = KWP_MESSAGE_FORMAT_ONE_BYTE_HEADER_ADDITIONAL_LENGTH;
        bytes[count++] = 0x00;  // empty
        bytes[count++] = length;
      }

      // Address header with format length byte
      else if ((keyByte1 & KWP_KEY1_LENGTH_IN_FORMAT_BYTE_SUPPORTED)) {
        messageFormat = KWP_MESSAGE_FORMAT_ADDRESS_HEADER_LENGTH_IN_FORMAT;
        bytes[count++] = 0xC0 | length;  // 80 = address information, 40 = functional addressing, length = 2
        bytes[count++] = 0x33;  // target (engine)
        bytes[count++] = 0xf1;  // source (diagnostic tools F0-FD)
      }

      // Address header with external length byte
      else {
        messageFormat = KWP_MESSAGE_FORMAT_ADDRESS_HEADER_ADDITIONAL_LENGTH;
        bytes[count++] = 0xc0;  // 80 = address information, 40 = functional addressing
        bytes[count++] = 0x33;  // target
        bytes[count++] = 0xf1;  // source (diagnostic tools F0-FD)
        bytes[count++] = length;
      }
      break;
  }

  bytes[count++] = mode;  // data1: mode
  if (pid || (mode == 1)) {
    bytes[count++] = pid;   // data2: pid
  }
  bytes[count] = getChecksum(bytes, 0, count-1);
  vserial.sendBytes(bytes, count+1, 10400, QUERY_SEND_DELAY_BETWEEN_BYTES);
}

extern long VObd::receivePidResponse(unsigned char pid, int mode, bool showErrors, int debugMode) {
  unsigned char bytes[4];
  int byteCount = receivePidResponseData(bytes, 4, pid, mode, showErrors, debugMode);
  long value = 0;

  lastPidRequestTime = millis();

  if (byteCount > 0) {
    for (int i = 0; i<byteCount && i<4; i++) {
      value = (long)bytes[i] | (value << 8);
    }
  } else {
    return byteCount;
  }
  return value;
}
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

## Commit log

2024-12-25 Update battery level multiplier
2024-12-25 Update battery voltage divider and add k+ pullup
2025-07-06 Add files via upload
    Fixed shift and mask values
    [ModularOBDGauge.ino, VObd.cpp]
2026-04-20 Added gear, horsepower, and g-force gauges
    * Added gear indicator
    * Added horsepower indicator
    * Added gforce indicator
    * Fixed some bugs with imperial/metric units and persistence
    * Restructured settings into submenus
    * Added settings menus to individually clear cumulative distance/fuel/time counters
    * Added settings menus to adjust cumulative distance/fuel/time counters
    * Added settings menus to set vehicle weight/mass
    * Added settings menus to set/adjust/autodetect vehicle gear shift points (by n/v ratio)
    * Added settings menus to set all gauges to imperial or metric at once
    * Software footprint now requires nano every
    * Adjust voltage divider values to match digital threshold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
    [ModularOBDGauge.ino]
2026-04-20 Updated case, angling back to reduce footprint
    [CommonUtils.scad, backAngle.stl, gaugeCaseParts.scad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]
2026-04-20 Updated to reflect Nano Every
    Updated voltage divider value and note to reflect voltage regulator no longer needed for Nano Every.
    [OBDGauge.kicad_pcb, OBDGauge.kicad_sch]
2026-04-20 Updates output for Nano Every
    [OBDGauge-B_Cu.gbr, OBDGauge-B_Mask.gbr, OBDGauge-B_Paste.gbr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]
2026-06-06 Add files via upload
    Fix mpg calculations
    [VObd.cpp, VObd.h]

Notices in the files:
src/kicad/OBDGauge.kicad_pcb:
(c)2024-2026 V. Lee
